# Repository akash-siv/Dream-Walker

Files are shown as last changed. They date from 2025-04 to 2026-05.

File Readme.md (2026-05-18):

# Low-Cost Wearable Solution for Mitigating VR Motion Sickness

## Project Summary
This project presents a low-cost wearable leg device leveraging embedded Tiny Machine Learning (TinyML) to mitigate Virtual Reality (VR) motion sickness by enabling standing-based locomotion control.

Video Title (https://www.youtube.com/watch?v=UUx8eebDtmY)

## Main Contributions
- Custom IMU dataset collected from 4 participants.
- Preprocessing using frequency-domain (FFT) and statistical feature extraction.
- Lightweight Deep Neural Network (DNN) trained and optimized for microcontroller deployment.
- End-to-end system achieving ~85% macro F1 score with under 100ms latency.
- Custom SteamVR driver integration with Bluetooth HID communication.

Authors:
--------
- Dhanush Balamurali (dhanushbalamurali@trentu.ca)
- Akash Sivasubramanian (akashsivasubramanian@trentu.ca)

Submission:
-----------
- This work is submitted as part of the AMOD Artificial Intelligence Project at Trent University, Peterborough, Canada.
- Submission includes all code, dataset, report, and driver files as required.

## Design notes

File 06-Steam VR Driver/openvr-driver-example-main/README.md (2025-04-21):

# Open VR Driver Example

This repository is an example on how to implement an Open VR driver that sends joystick and/or trackpad input to Open VR. This input will move the game character. This sample is simply hard coded to constantly send forward joystick and trackpad input to Open VR, causing the game character to constantly move foward just like if you were using a regular VR controller and holding the joystick/trackpad forward. You can take this example and replace the hardcoded move foward code with code that actually gets output from a device, such as a VR treadmill, VR shoes [like mine](https://github.com/finallyfunctional/vr-shoes-software), VR shoes like [CyberShoes](https://www.cybershoes.io/), or VR sensors similar to [Kat Loco](https://www.kat-vr.com/products/KAT-loco).

I created this sample and wrote lots of documentation in this [repository's wiki](https://github.com/finallyfunctional/openvr-driver-example/wiki) because I found the [existing OpenVR documentation](https://github.com/ValveSoftware/openvr/wiki/Driver-Documentation) and [driver sample](https://github.com/ValveSoftware/openvr/tree/master/samples/driver_sample) to be lacking. It was hard to create this sample initially, not knowing anything about OpenVR. I had to slowly piece together over many hours information from the documentation, sample, and other samples and Open VR implementations I found online to make this driver sample that simply moves the character forward. My hope is that this sample and the documentation I provide here will make it easier for complete beginners to start using Open VR.

open vr driver is forked from finally functional github repo and altered a bit based on this [blog](https://petersen-projects.com/?p=30)

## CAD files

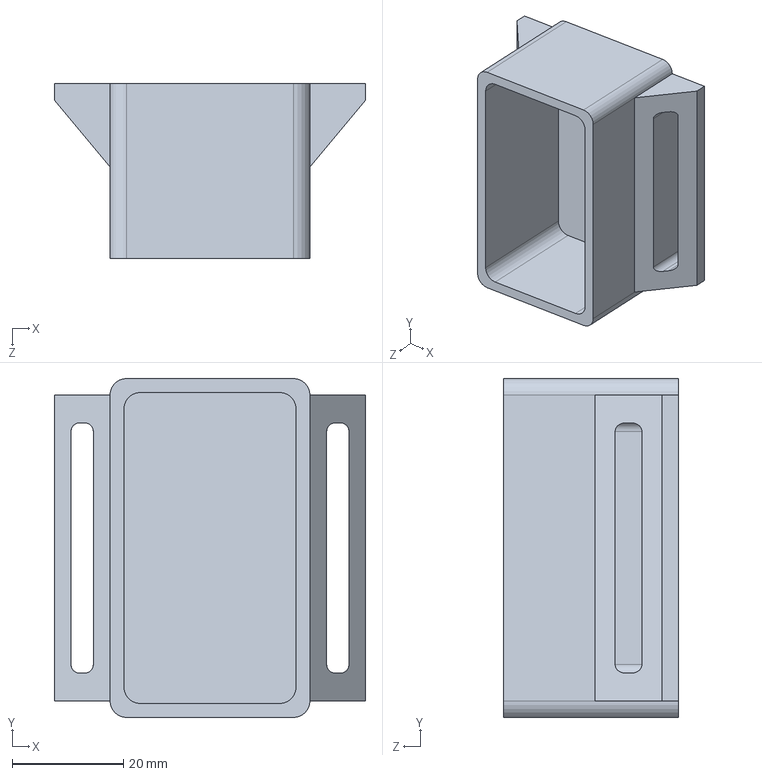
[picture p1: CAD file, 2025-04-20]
04-Enclosure 3D prints/Encloseure base.SLDPRT
56.0 x 61.0 x 31.5 mm

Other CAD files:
04-Enclosure 3D prints/project_enclosure_v3.3mf
04-Enclosure 3D prints/project_enclosure_v3.STL

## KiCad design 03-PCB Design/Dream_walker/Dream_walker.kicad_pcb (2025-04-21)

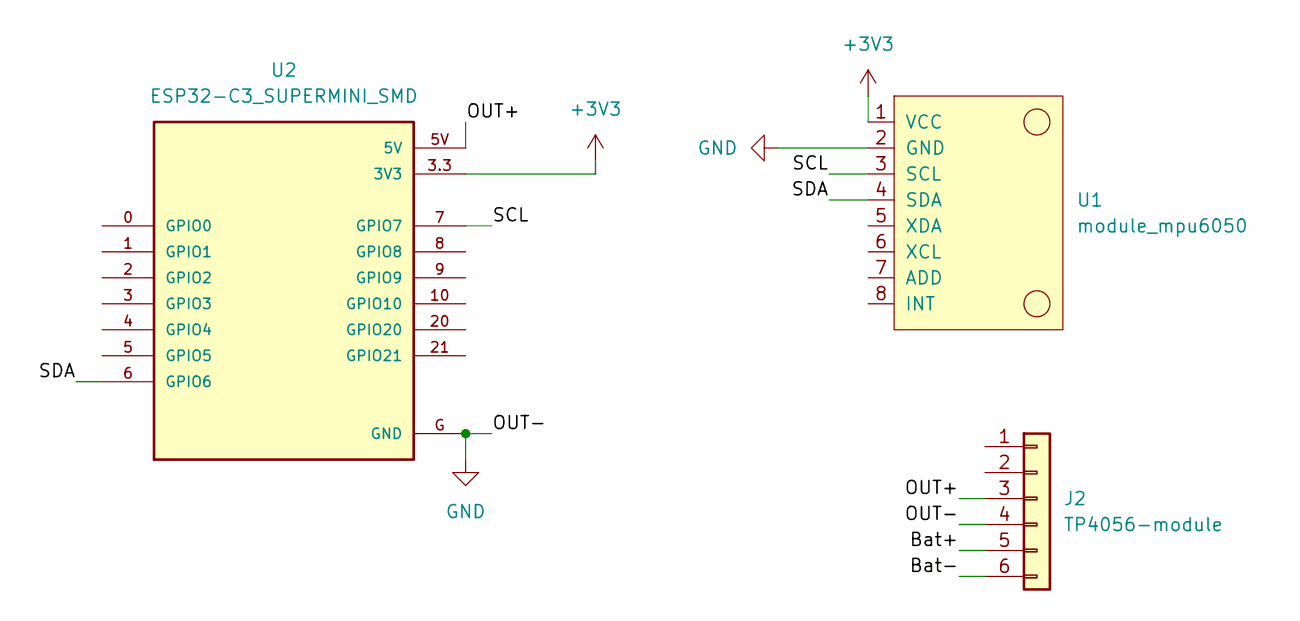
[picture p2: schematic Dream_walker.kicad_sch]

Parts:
J2: TP4056-module; tp4056-module
U1: module_mpu6050
U2: ESP32-C3_SUPERMINI_SMD; MODULE_ESP32-C3_SUPERMINI

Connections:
+3V3: U1.1 (VCC), U2.3.3 (3V3)
/Bat+: J2.5
/Bat-: J2.6
/OUT+: J2.3, U2.5V
/SCL: U1.3 (SCL), U2.7 (GPIO7)
/SDA: U1.4 (SDA), U2.6 (GPIO6)
GND: J2.4, U1.2 (GND), U2.G (GND)

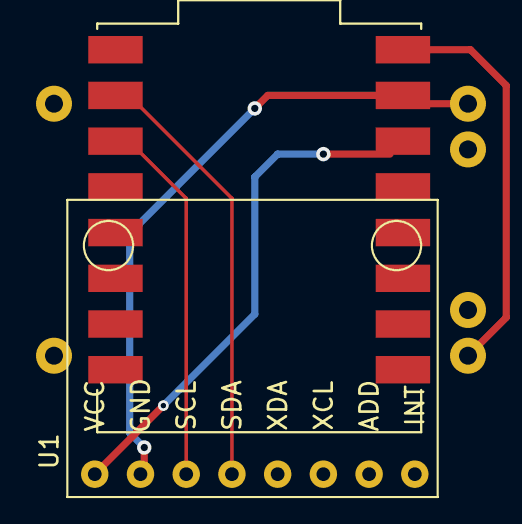
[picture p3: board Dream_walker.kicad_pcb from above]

Board: 2 copper layers, 3 parts (1 on the bottom side), 5 nets.

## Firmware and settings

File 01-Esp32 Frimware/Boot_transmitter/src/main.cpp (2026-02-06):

#include <Arduino.h>
#include <MPU9250_asukiaaa.h>
#include <esp_now.h>
#include <WiFi.h>
#include <VR_Walk-in-place_controller_inferencing.h>
#include <BleKeyboard.h>

#include "freertos/FreeRTOS.h"
#include "freertos/queue.h"

#ifdef _ESP32_HAL_I2C_H_
#define SDA_PIN 21
#define SCL_PIN 22
#endif

BleKeyboard bleKeyboard("Dream Walker");

// Data structure for sensor readings
typedef struct struct_message {
  float accelX, accelY, accelZ;
  float gyroX, gyroY, gyroZ;
} struct_message;

// Queue handle (global)
static QueueHandle_t dataQueue = NULL;
#define QUEUE_LENGTH 1   // keep only the latest packet
#define QUEUE_ITEM_SIZE sizeof(struct_message)

MPU9250_asukiaaa mySensor;

uint8_t senderMAC[] = {0x78, 0x42, 0x1C, 0x67, 0x34, 0xF0};

#define TOTAL_FEATURES EI_CLASSIFIER_DSP_INPUT_FRAME_SIZE
float feature_buffer[TOTAL_FEATURES];
size_t feature_idx = 0;

bool isWalking = false; // flag for tracking key state

void print_inference_result(ei_impulse_result_t result);

// ESP-NOW receive callback (runs in WiFi task context)
void OnDataRecv(const uint8_t *mac, const uint8_t *incomingData, int len) {
  // quick checks
  if (memcmp(mac, senderMAC, 6) != 0) return;
  if (len < (int)sizeof(struct_message)) return;

  struct_message msg;
  memcpy(&msg, incomingData, sizeof(msg));

  // Since queue length == 1, overwrite keeps the latest sample.
  // xQueueOverwrite can only be used safely on a 1-item queue.
  if (dataQueue != NULL) {
    xQueueOverwrite(dataQueue, &msg);
  }
}

int raw_feature_get_data(size_t offset, size_t length, float *out_ptr) {
  memcpy(out_ptr, feature_buffer + offset, length * sizeof(float));
  return 0;
}

void setup() {
  Serial.begin(115200);
  while (!Serial);

  Serial.println("Edge Impulse BLE Keyboard Demo (Queue-enabled)");

  bleKeyboard.begin();

  // create queue BEFORE registering callback so callback can safely use it
  dataQueue = xQueueCreate(QUEUE_LENGTH, QUEUE_ITEM_SIZE);
  if (dataQueue == NULL) {
    Serial.println("ERROR: queue creation failed!");
    while (1) { delay(1000); } // fatal
  }

  WiFi.mode(WIFI_STA);
  if (esp_now_init() != ESP_OK) {
    Serial.println("ESP-NOW init failed!");
    return;
  }
  esp_now_register_recv_cb(OnDataRecv);

#ifdef _ESP32_HAL_I2C_H_
  Wire.begin(SDA_PIN, SCL_PIN);
  mySensor.setWire(&Wire);
#endif

  mySensor.beginAccel(ACC_FULL_SCALE_4_G);
  mySensor.beginGyro();
}

void loop() {
  struct_message remoteData; // local consumer buffer
  bool gotPacket = false;

  // Try to receive the latest packet (non-blocking)
  if (dataQueue != NULL) {
    if (xQueueReceive(dataQueue, &remoteData, 0) == pdTRUE) {
      gotPacket = true;
    }
  }

  // read local IMU 
  if (mySensor.accelUpdate() == 0 && mySensor.gyroUpdate() == 0) {
    // success
  } else {
    Serial.println("Failed to read from local IMU");
    return;
  }

  // read current local data into localData variables
  struct_message localData;
  localData.accelX = mySensor.accelX();
  localData.accelY = mySensor.accelY();
  localData.accelZ = mySensor.accelZ();
  localData.gyroX  = mySensor.gyroX();
  localData.gyroY  = mySensor.gyroY();
  localData.gyroZ  = mySensor.gyroZ();

  if (gotPacket) {
    // Append incoming + local features into feature_buffer exactly like before
    if (feature_idx + 12 <= TOTAL_FEATURES) {
      feature_buffer[feature_idx++] = remoteData.accelX;
      feature_buffer[feature_idx++] = remoteData.accelY;
      feature_buffer[feature_idx++] = remoteData.accelZ;
      feature_buffer[feature_idx++] = remoteData.gyroX;
      feature_buffer[feature_idx++] = remoteData.gyroY;
      feature_buffer[feature_idx++] = remoteData.gyroZ;

      feature_buffer[feature_idx++] = localData.accelX;
      feature_buffer[feature_idx++] = localData.accelY;
      feature_buffer[feature_idx++] = localData.accelZ;
      feature_buffer[feature_idx++] = localData.gyroX;
      feature_buffer[feature_idx++] = localData.gyroY;
      feature_buffer[feature_idx++] = localData.gyroZ;
    }

    if (feature_idx >= TOTAL_FEATURES) {
      ei_impulse_result_t result = {0};
      signal_t features_signal;
      features_signal.total_length = TOTAL_FEATURES;
      features_signal.get_data = &raw_feature_get_data;

      EI_IMPULSE_ERROR res = run_classifier(&features_signal, &result, false);
      if (res != EI_IMPULSE_OK) {
        Serial.println("ERR: Classifier failed!");
        feature_idx = 0;
        return;
      }

      print_inference_result(result);

      float walkConfidence = 0;
      float otherMaxConfidence = 0;

      for (uint16_t i = 0; i < EI_CLASSIFIER_LABEL_COUNT; i++) {
        String label = String(ei_classifier_inferencing_categories[i]);
        float value = result.classification[i].value * 100;

        if (label.equalsIgnoreCase("walk")) {
          walkConfidence = value;
        } else {
          otherMaxConfidence = max(otherMaxConfidence, value);
        }
      }

      // BLE Keyboard Logic
      if (bleKeyboard.isConnected()) {
        if (walkConfidence >= 90.0 && !isWalking) {
          Serial.println("Walking detected! Sending 'W'...");
          bleKeyboard.press('w');
          isWalking = true;
        } else if (otherMaxConfidence >= 90.0 && isWalking) {
          Serial.println("Stop detected! Releasing 'W'...");
          bleKeyboard.release('w');
          isWalking = false;
        }
      } else {
        Serial.println("BLE Keyboard not connected!");
      }

      feature_idx = 0;  // Reset buffer after inference
    }
  }


}

void print_inference_result(ei_impulse_result_t result) {
  Serial.printf("\n DSP: %d ms | Inferencing: %d ms | Anomaly: %d ms\n",
                result.timing.dsp,
                result.timing.classification,
                result.timing.anomaly);

  Serial.println("Predictions:");
  for (uint16_t i = 0; i < EI_CLASSIFIER_LABEL_COUNT; i++) {
    Serial.printf(" • %s: %.5f\n",
                  ei_classifier_inferencing_categories[i],
                  result.classification[i].value);
  }

#if EI_CLASSIFIER_HAS_ANOMALY
  Serial.printf("Anomaly: %.3f\n", result.anomaly);
#endif
}

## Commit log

2025-04-20 code organized
    [Encloseure base.SLDPRT, project_enclosure_v3.3mf, project_enclosure_v3.STL]
2025-04-21 added pcb files
    [Dream_walker.kicad_pcb, Dream_walker.kicad_sch]
